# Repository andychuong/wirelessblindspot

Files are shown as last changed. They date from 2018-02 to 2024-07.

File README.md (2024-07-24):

# Wireless Blindspot Detection System

This project was designed to be an easy to install/use blindspot detection system for motor vehicles. It was inspired by the advances of technology and computed embedded into modern cars. 

This project is comprised of two unites, a receiver and a sensor. The sensor unit is attached to your rear quarter panel with a magnet and has an ultrasonic sensor attached to it. The receiver component is made to sit inside of your car with an array of LED lights to notify the driver of objects in their blindspot. 

## Technology
- Arduino
- Bluetooth
- Eagle CAD

## Hardware
- [2x SparkFun ProMicro 5v](https://www.sparkfun.com/products/12640)
- [2x xBee](https://www.sparkfun.com/products/8665)
- [Weatherproof Ultrasonic Sensor](https://www.amazon.com/Waterproof-Ultrasonic-Distance-Measuring-Transducer/dp/B01J5KZU8M)
- [Individually Addressable LED Strip](https://www.amazon.com/ALITOVE-WS2812B-Individually-Addressable-Waterproof/dp/B00ZHB9M6A)

## Images
More images [here](https://github.com/andychuong/wirelessblindspot/tree/master/Images)
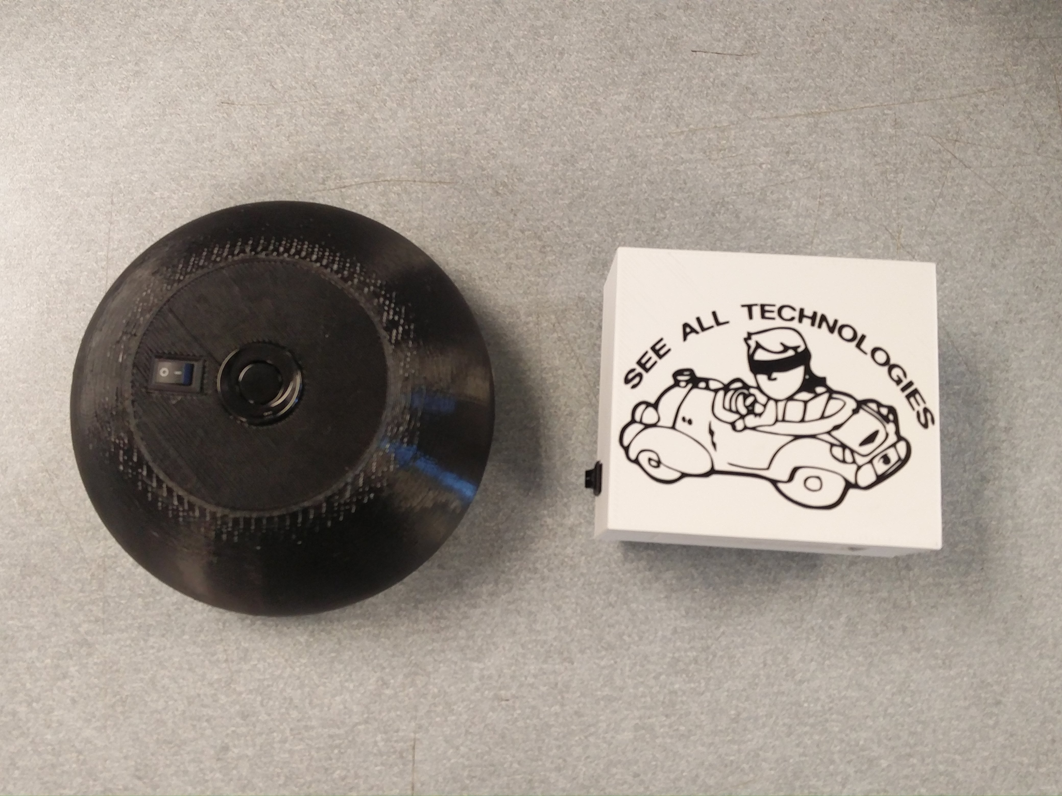
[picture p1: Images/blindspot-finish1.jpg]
Complete Units

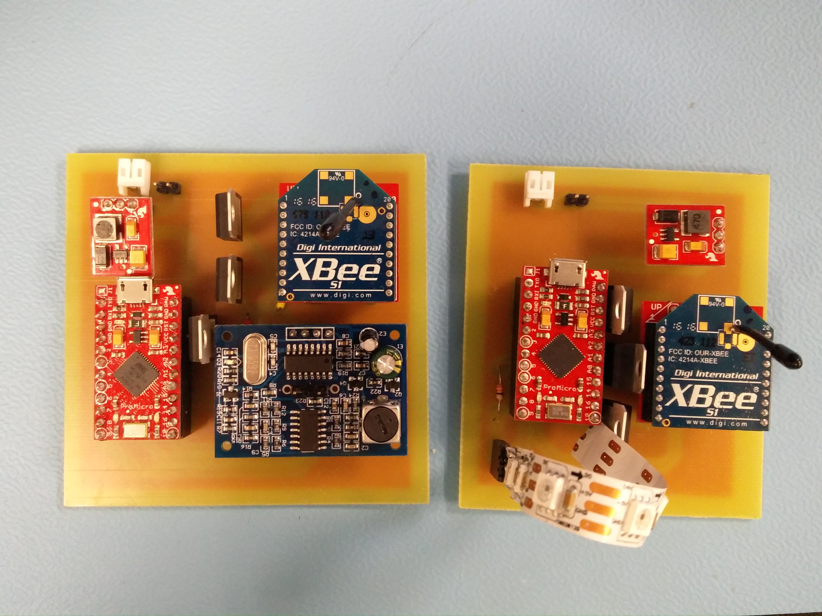
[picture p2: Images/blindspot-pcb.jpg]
Circuit boards


## Going Futher
### Built in charging solution
Currently, this project has you remove the LiPo batteries and plug them in a charger when they are out of charge. In the future, it would be nice to implement some kind of integrated setup to allow users to charge the batteries without disassembling the units. 
### Weather Proofing
The sensor unit that is attached to the exterious of the vehicle would need to have some sort of weatherproofing added to it. The addition of some sort of gaskets would greatly improve this. 
### Size Reduction
The footprint of our units isn't overly large, however I believe the size can be greatly reduced. To improve this, my first though would be to use a microcontroller such as the Adafruit Feather Bluefruit. This would combine our microcontroller with our bluetooth units. This would also solve our charging situation. Another idea would be to completely build our own circuit boards with everything we need implemented into the PCB with surface mounted components. 

---
###### Done in collaboration with Sean Connolly, Elijah Fisk, and Alex Schwartz.

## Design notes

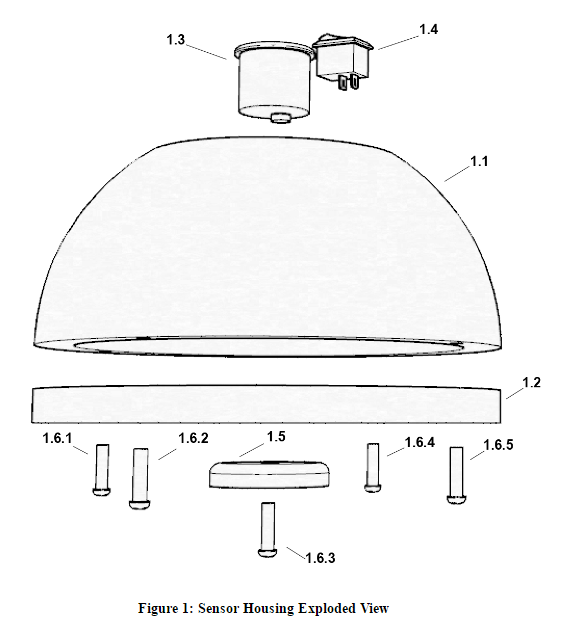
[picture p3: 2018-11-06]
Images/blindspot-sensor-exploded.png

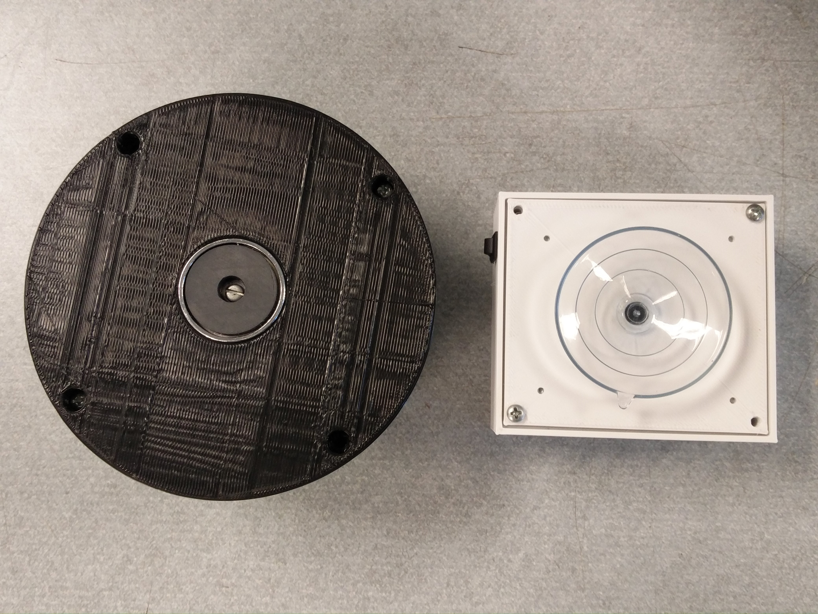
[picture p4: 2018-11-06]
Images/blindspot-finish2.jpg

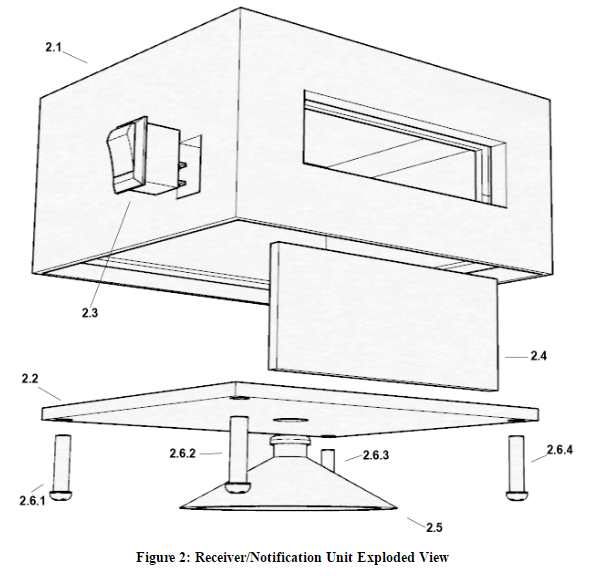
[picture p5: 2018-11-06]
Images/blindspot-receiver-exploded.png

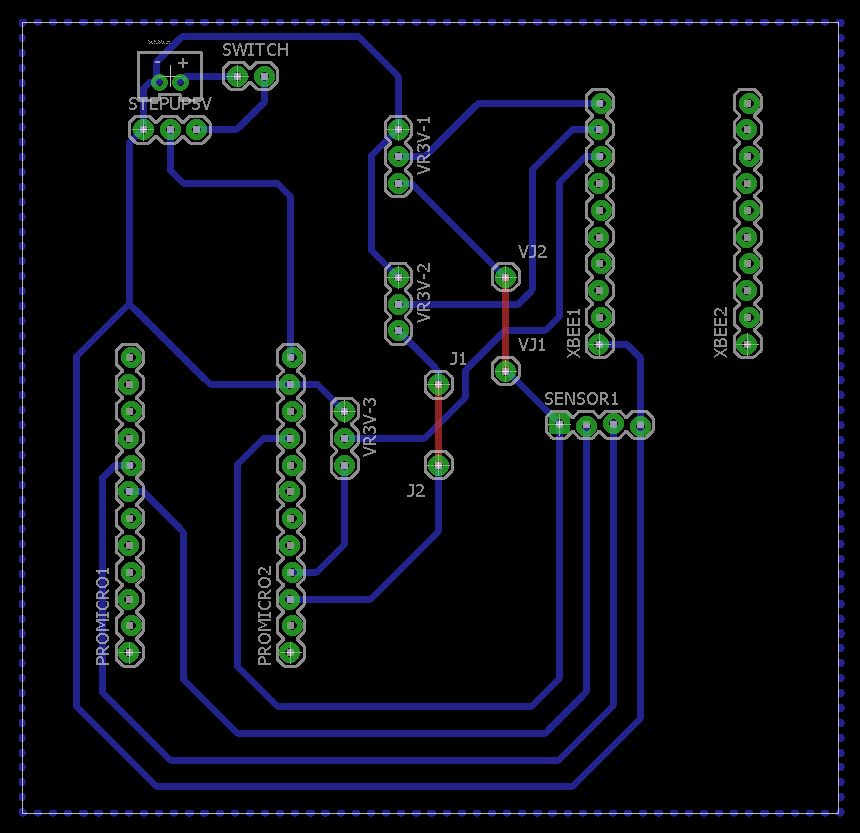
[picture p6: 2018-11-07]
Images/blindspot-sensor-eagle.png

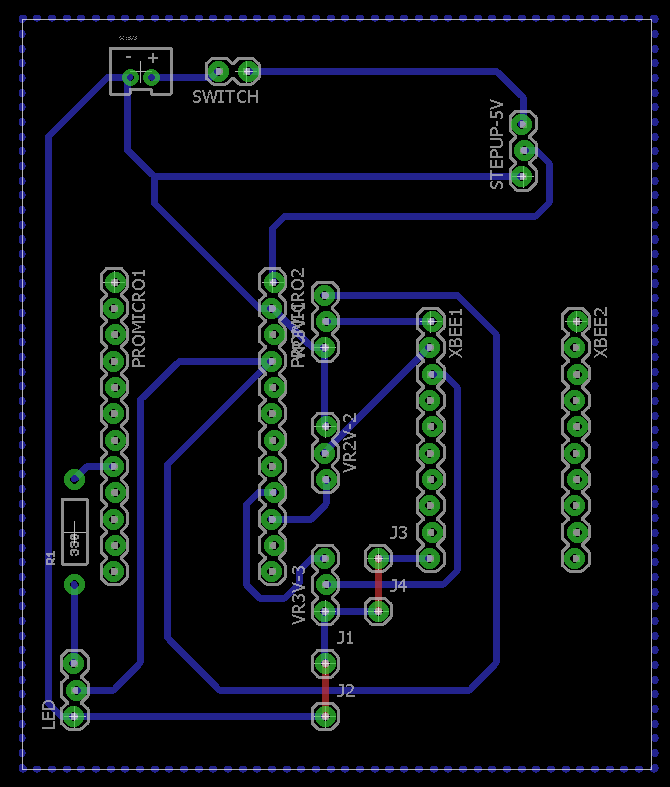
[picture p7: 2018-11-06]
Images/blindspot-receiver-eagle.png

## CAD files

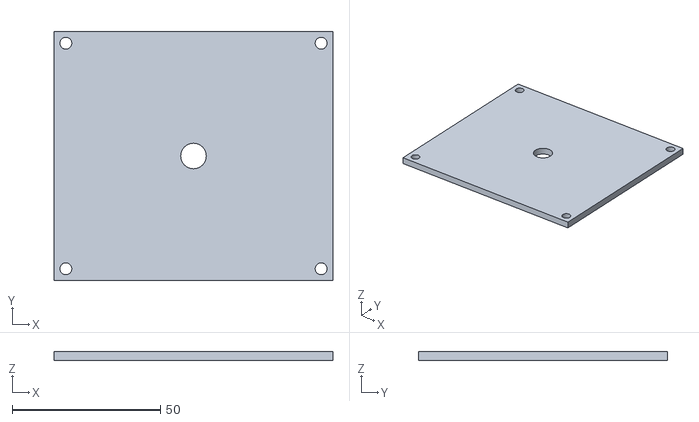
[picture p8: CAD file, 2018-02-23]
Enclosures/stl/lid.stl
94.0 x 84.0 x 3.00

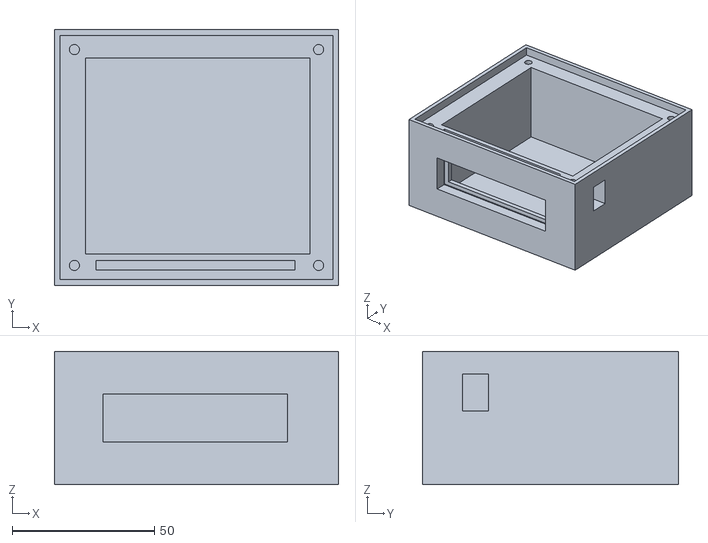
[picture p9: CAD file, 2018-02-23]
Enclosures/stl/box.stl
100.0 x 90.0 x 47.0

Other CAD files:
Enclosures/ReceiverComponentsExploded.3dm
Enclosures/SensorComponentsExploded.3dm
Enclosures/receiverEnclosure.3dm
Enclosures/sensorEnclosure.3dm

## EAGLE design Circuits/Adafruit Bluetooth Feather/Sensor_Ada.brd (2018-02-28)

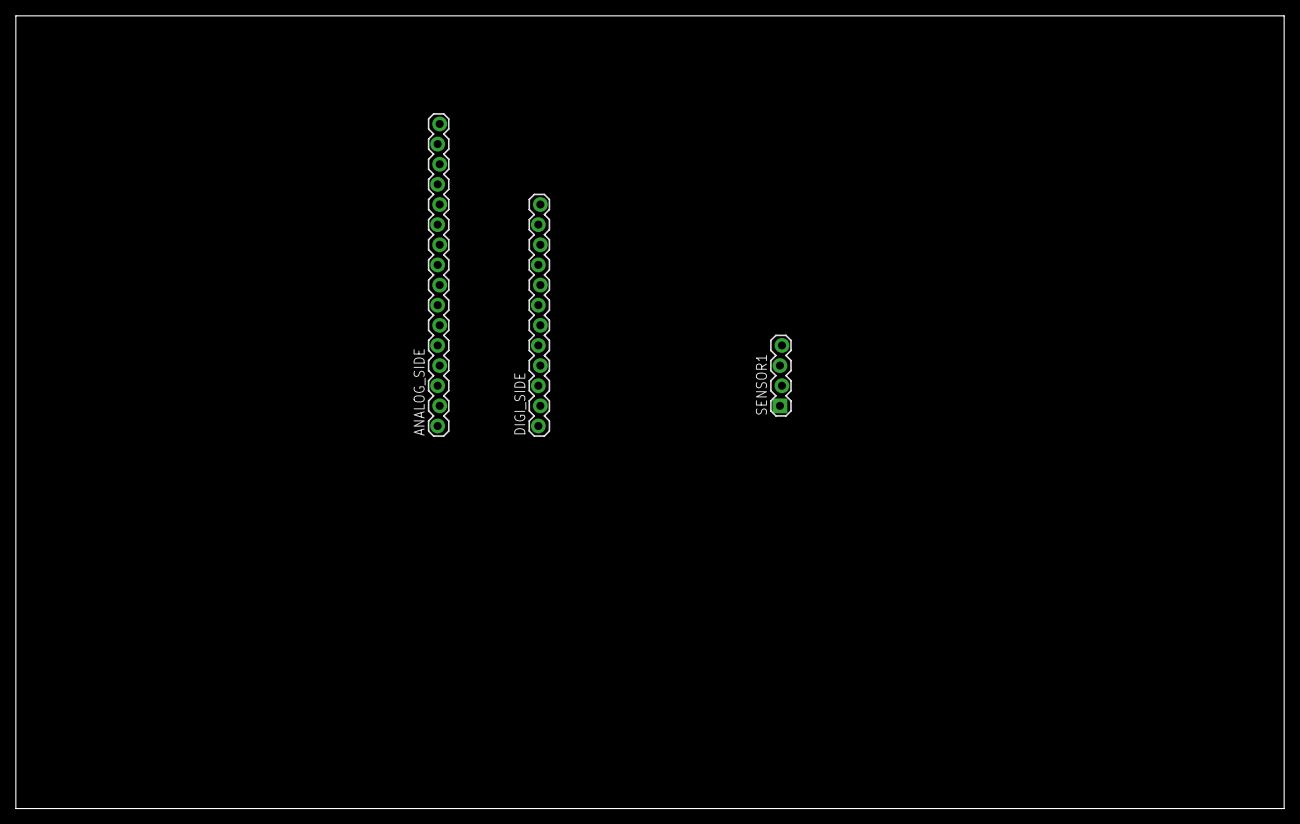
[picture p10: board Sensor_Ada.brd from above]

Board: 2 copper layers, 160.0 x 100.0 mm, 3 parts (0 on the bottom side), 3 nets, no tracks yet.

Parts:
ANALOG_SIDE: 1X16_LOCK
DIGI_SIDE: 1X12_LOCK
SENSOR1: 1X04_LOCK

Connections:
ECHO: DIGI_SIDE.1, SENSOR1.2
GND: ANALOG_SIDE.13, SENSOR1.1
TRIG: DIGI_SIDE.2, SENSOR1.3

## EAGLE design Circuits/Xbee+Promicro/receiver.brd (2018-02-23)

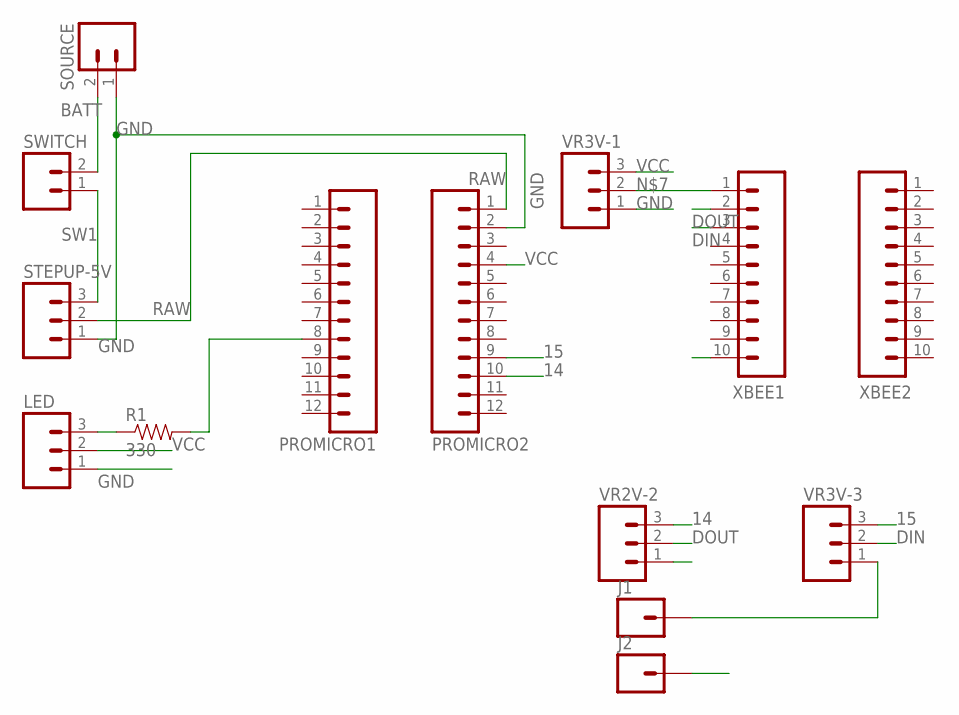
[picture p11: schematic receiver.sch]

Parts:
J1, J2: M01PTH; 1X01
LED: M03LOCK; 1X03_LOCK
PROMICRO1, PROMICRO2: M12LOCK; 1X12_LOCK
R1: 330; AXIAL-0.4
SOURCE: M02JST-PTH-VERT; JST-2-PTH-VERT
STEPUP-5V: M03LOCK; 1X03_LOCK
SWITCH: M02LOCK; 1X02_LOCK
VR2V-2, VR3V-1, VR3V-3: M03LOCK; 1X03_LOCK
XBEE1, XBEE2: M10LOCK; 1X10_LOCK

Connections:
14: PROMICRO2.10, VR2V-2.3
15: PROMICRO2.9, VR3V-3.3
BATT: SOURCE.2, SWITCH.2
DIN: VR3V-3.2, XBEE1.3
DOUT: VR2V-2.2, XBEE1.2
GND: J1.1, J2.1, LED.1, PROMICRO2.2, SOURCE.1, STEPUP-5V.1, VR2V-2.1, VR3V-1.1, VR3V-3.1
unnamed: LED.3, R1.P$1 (1)
unnamed: PROMICRO1.8, R1.P$2 (2)
unnamed: VR3V-1.2, XBEE1.1
RAW: PROMICRO2.1, STEPUP-5V.2
SW1: STEPUP-5V.3, SWITCH.1
VCC: LED.2, PROMICRO2.4, VR3V-1.3

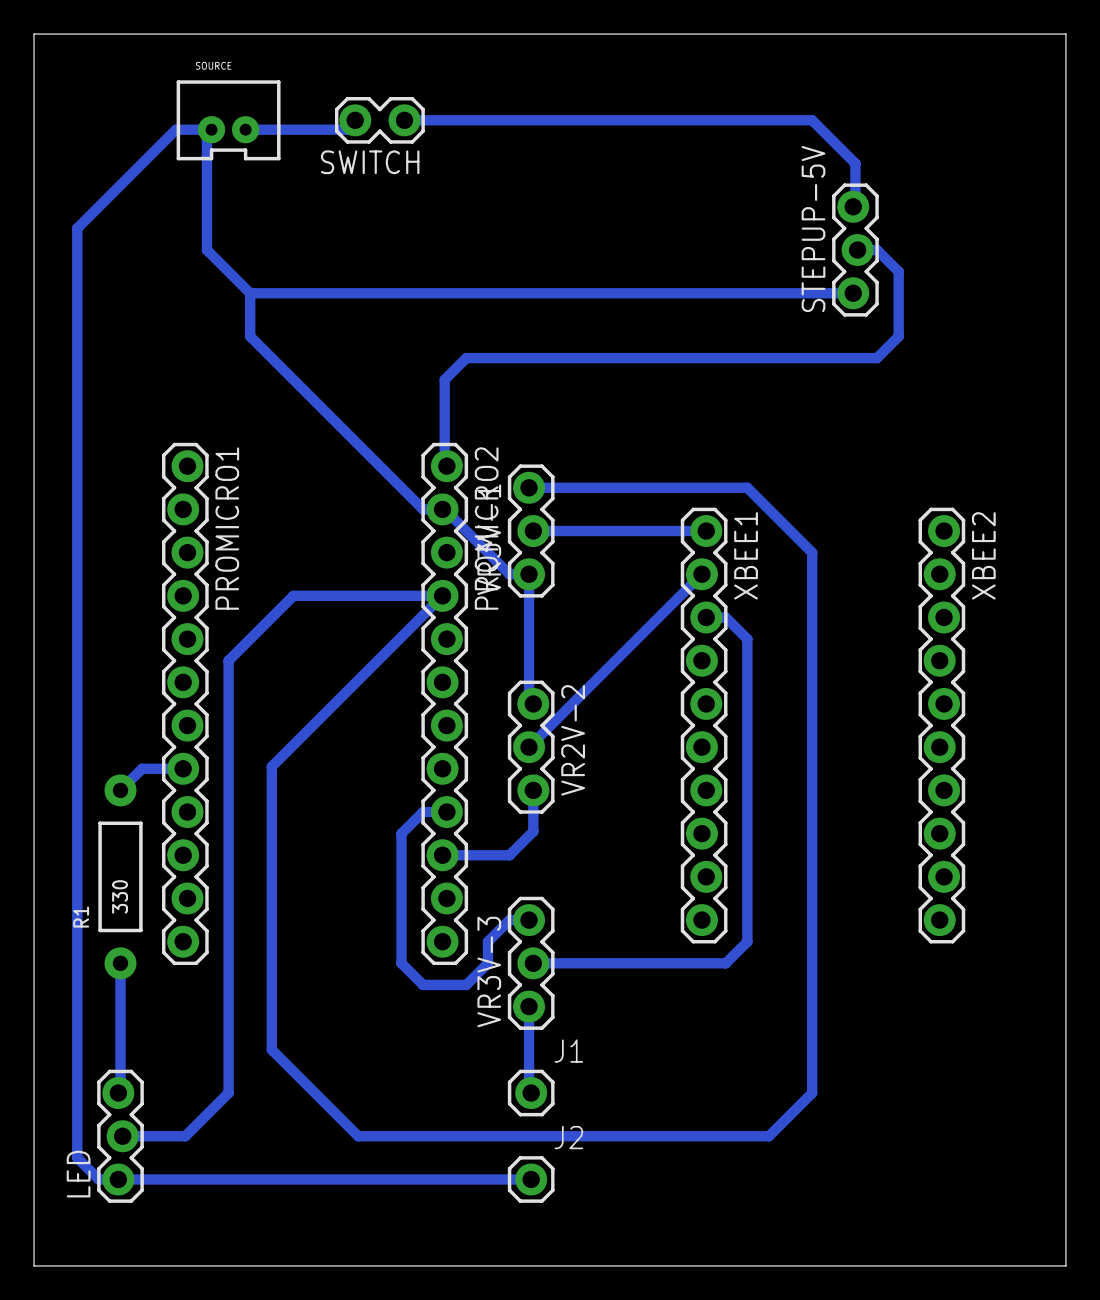
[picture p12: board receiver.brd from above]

Board: 2 copper layers, 60.6 x 72.4 mm, 14 parts (0 on the bottom side), 12 nets.

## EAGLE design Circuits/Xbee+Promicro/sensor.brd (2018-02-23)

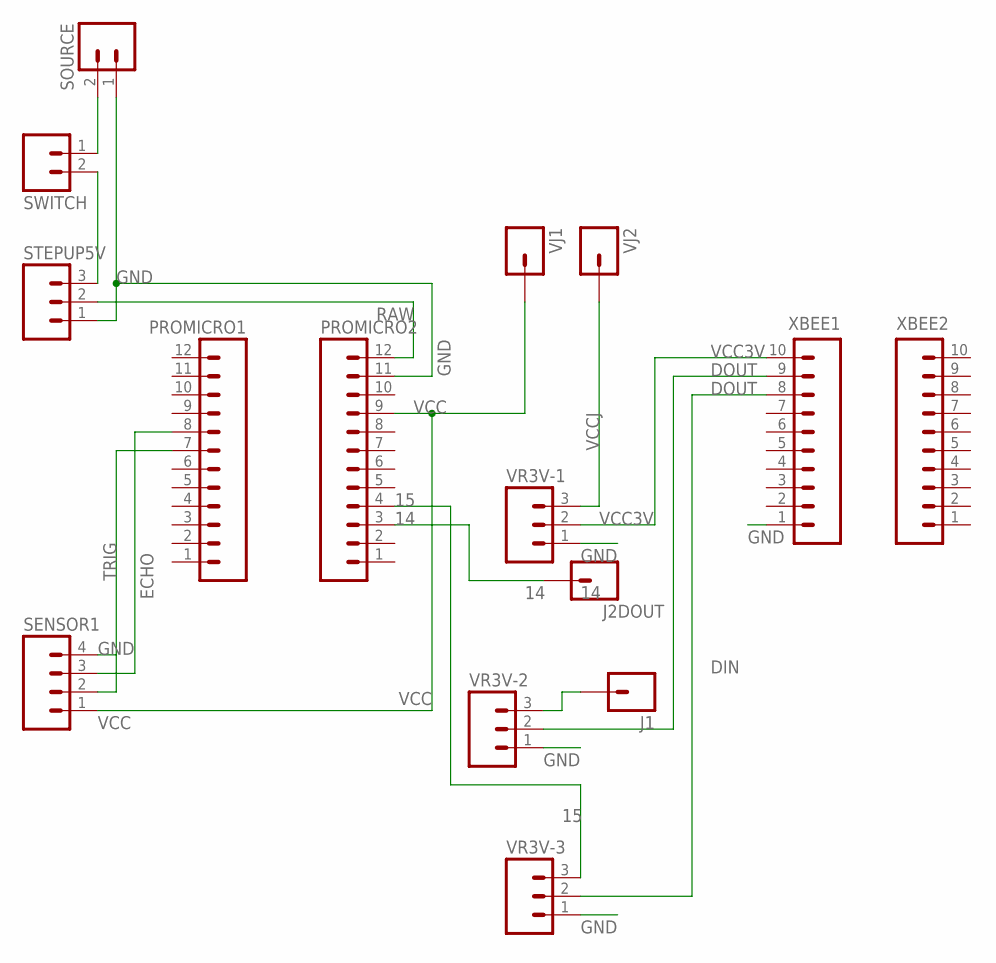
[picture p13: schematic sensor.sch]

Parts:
J1, J2: M01PTH; 1X01
PROMICRO1, PROMICRO2: M12LOCK; 1X12_LOCK
SENSOR1: M04LOCK; 1X04_LOCK
SOURCE: M02JST-PTH-VERT; JST-2-PTH-VERT
STEPUP5V: M03PTH; 1X03
SWITCH: M02PTH; 1X02
VJ1, VJ2: M01PTH; 1X01
VR3V-1, VR3V-2, VR3V-3: M03PTH; 1X03
XBEE1, XBEE2: M10LOCK; 1X10_LOCK

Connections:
14: J2.1, PROMICRO2.3
15: PROMICRO2.4, VR3V-3.3
DIN: VR3V-3.2, XBEE1.8
DOUT: VR3V-2.2, XBEE1.9
ECHO: PROMICRO1.8, SENSOR1.3
GND: PROMICRO2.11, SENSOR1.4, SOURCE.1, STEPUP5V.1, VR3V-1.1, VR3V-2.1, VR3V-3.1, XBEE1.1
unnamed: SOURCE.2, SWITCH.1
unnamed: STEPUP5V.3, SWITCH.2
unnamed: J1.1, VR3V-2.3
RAW: PROMICRO2.12, STEPUP5V.2
TRIG: PROMICRO1.7, SENSOR1.2
VCC: PROMICRO2.9, SENSOR1.1, VJ1.1
VCC3V: VR3V-1.2, XBEE1.10
VCCJ: VJ2.1, VR3V-1.3

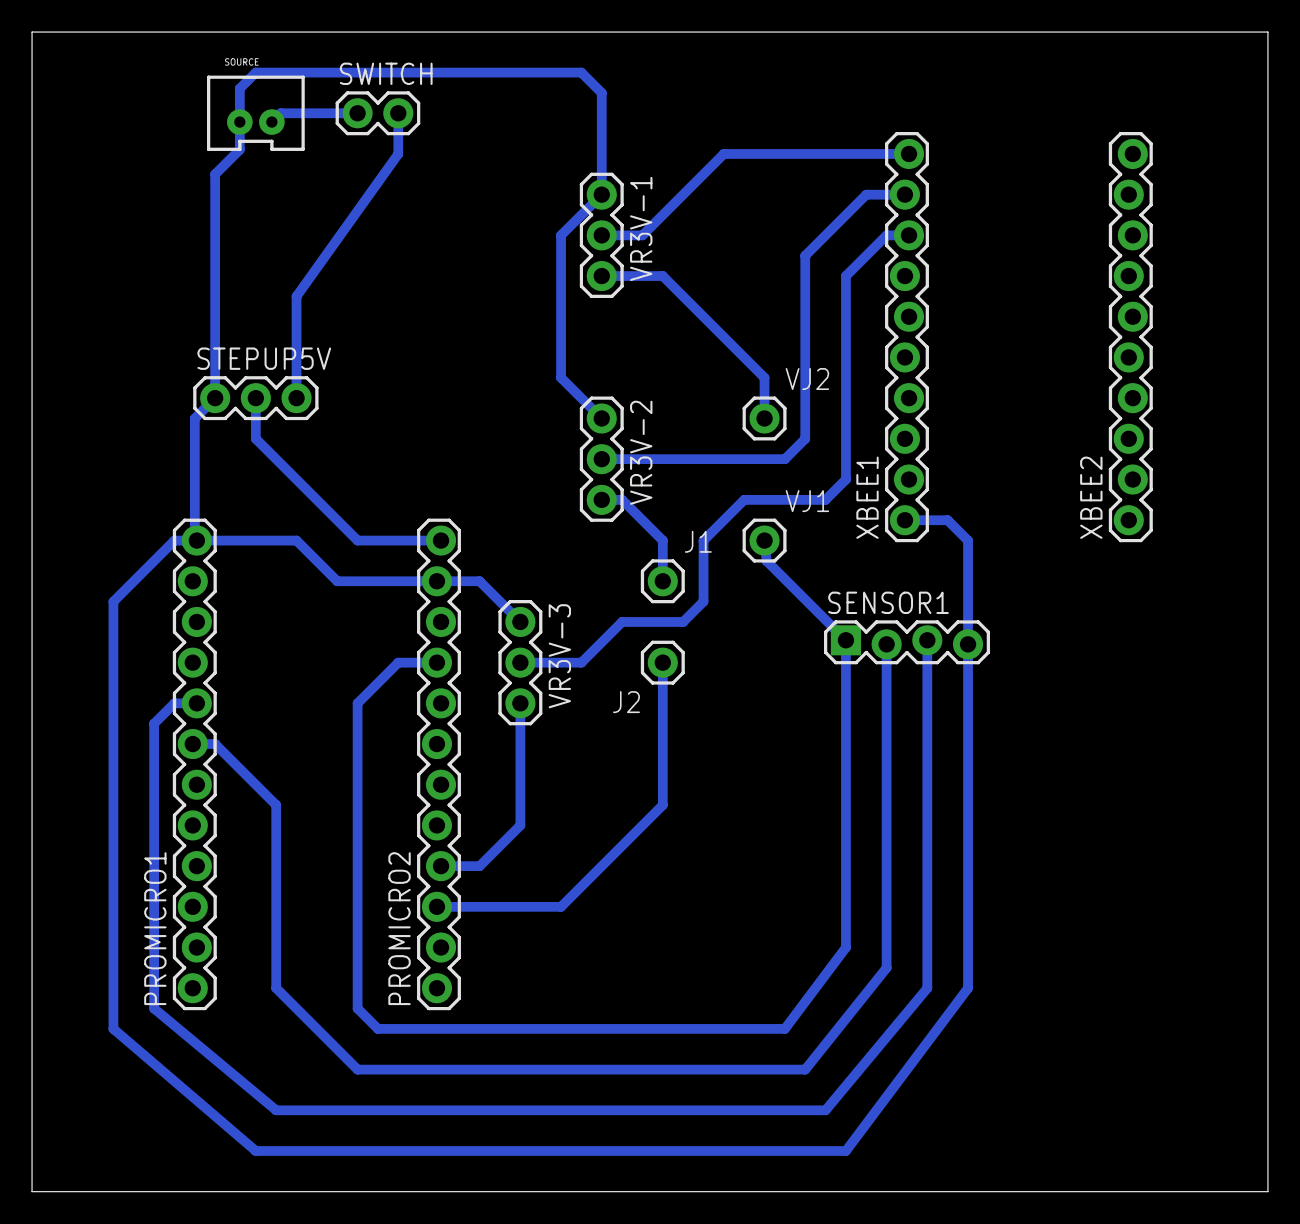
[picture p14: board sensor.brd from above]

Board: 2 copper layers, 77.1 x 72.4 mm, 15 parts (0 on the bottom side), 14 nets.

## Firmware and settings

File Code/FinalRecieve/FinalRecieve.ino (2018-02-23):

/*****************************************************************
XBee_Serial_Passthrough.ino

Set up a software serial port to pass data between an XBee Shield
and the serial monitor.

Hardware Hookup:
  The XBee Shield makes all of the connections you'll need
  between Arduino and XBee. If you have the shield make
  sure the SWITCH IS IN THE "DLINE" POSITION. That will connect
  the XBee's DOUT and DIN pins to Arduino pins 2 and 3.

*****************************************************************/

#include <Adafruit_NeoPixel.h>
#ifdef __AVR__
  #include <avr/power.h>
#endif

#define PIN 5

// Parameter 1 = number of pixels in strip
// Parameter 2 = Arduino pin number (most are valid)
// Parameter 3 = pixel type flags, add together as needed:
//   NEO_KHZ800  800 KHz bitstream (most NeoPixel products w/WS2812 LEDs)
//   NEO_KHZ400  400 KHz (classic 'v1' (not v2) FLORA pixels, WS2811 drivers)
//   NEO_GRB     Pixels are wired for GRB bitstream (most NeoPixel products)
//   NEO_RGB     Pixels are wired for RGB bitstream (v1 FLORA pixels, not v2)
//   NEO_RGBW    Pixels are wired for RGBW bitstream (NeoPixel RGBW products)
Adafruit_NeoPixel strip = Adafruit_NeoPixel(7, PIN, NEO_GRB + NEO_KHZ800);

// IMPORTANT: To reduce NeoPixel burnout risk, add 1000 uF capacitor across
// pixel power leads, add 300 - 500 Ohm resistor on first pixel's data input
// and minimize distance between Arduino and first pixel.  Avoid connecting
// on a live circuit...if you must, connect GND first.


// We'll use SoftwareSerial to communicate with the XBee:
#include <SoftwareSerial.h>
// XBee's DOUT (TX) is connected to pin 2 (Arduino's Software RX)
// XBee's DIN (RX) is connected to pin 3 (Arduino's Software TX)
SoftwareSerial XBee(14, 15); // RX, TX
const int numReadings = 10;
int readingsa[numReadings];      // the readings from the analog input
int readIndex = 0;              // the index of the current reading
int totala = 0;                  // the running total
int averagea = 0;                // the average


void setup()
{
  // Set up both ports at 9600 baud. This value is most important
  // for the XBee. Make sure the baud rate matches the config
  // setting of your XBee.
  XBee.begin(9600);
  Serial.begin(9600);
  for (int thisReading = 0; thisReading < numReadings; thisReading++) {
    readingsa[thisReading] = 0;
  }
  
  strip.begin();
  strip.show(); // Initialize all pixels to 'off'
}

void loop()
{
  /*if (Serial.available())
  { // If data comes in from serial monitor, send it out to XBee
    XBee.write(Serial.read());
  }*/
  
  if (XBee.available())
  { // If data comes in from XBee, send it out to serial monitor
   int dist = XBee.read();
   if (dist==244)
   {
   dist=500;
   
   }
    totala = totala - readingsa[readIndex];
  // read from the sensor:
  readingsa[readIndex] = dist;
  // add the reading to the total:
  totala = totala + readingsa[readIndex];
   // advance to the next position in the array:
  readIndex = readIndex + 1;

  // if we're at the end of the array...
  if (readIndex >= numReadings) {
    // ...wrap around to the beginning:
    readIndex = 0;
  }

  // calculate the average:
    averagea = totala / numReadings;
  //  averagey = totaly / numReadings;
    //averagez = totalz / numReadings;
  
  Serial.print(dist);
  Serial.print("\t");
  Serial.println(averagea);
  if (averagea>200)
  {
  colorWipe(strip.Color(127, 127, 127), 10); // White
  }
   /* else if (101<averagea<450){
     colorWipe(strip.Color(0, 127, 0), 10); // Green 
    }
      else if (51<averagea<100){
      colorWipe(strip.Color(127, 127, 0), 10); // Yellow  
  }
  */
        else if (averagea<200) {
  colorWipe(strip.Color(127, 0, 0), 10); // Red  
  
  }
  delay(100);
    }
    else{
        rainbow(5); 
    }
}


// Fill the dots one after the other with a color
void colorWipe(uint32_t c, uint8_t wait) {
  for(uint16_t i=0; i<strip.numPixels(); i++) {
    strip.setPixelColor(i, c);
    strip.show();
    delay(wait);
  }
}

void rainbow(uint8_t wait) {
  uint16_t i, j;

  for(j=0; j<256; j++) {
    for(i=0; i<strip.numPixels(); i++) {
      strip.setPixelColor(i, Wheel((i+j) & 255));
    }
    strip.show();
    delay(wait);
  }
}

//Theatre-style crawling lights.
void theaterChase(uint32_t c, uint8_t wait) {
  for (int j=0; j<10; j++) {  //do 10 cycles of chasing
    for (int q=0; q < 3; q++) {
      for (int i=0; i < strip.numPixels(); i=i+3) {
        strip.setPixelColor(i+q, c);    //turn every third pixel on
      }
      strip.show();

      delay(wait);

      for (int i=0; i < strip.numPixels(); i=i+3) {
        strip.setPixelColor(i+q, 0);        //turn every third pixel off
      }
    }
  }
}

uint32_t Wheel(byte WheelPos) {
  WheelPos = 255 - WheelPos;
  if(WheelPos < 85) {
    return strip.Color(255 - WheelPos * 3, 0, WheelPos * 3);
  }
  if(WheelPos < 170) {
    WheelPos -= 85;
    return strip.Color(0, WheelPos * 3, 255 - WheelPos * 3);
  }
  WheelPos -= 170;
  return strip.Color(WheelPos * 3, 255 - WheelPos * 3, 0);
}

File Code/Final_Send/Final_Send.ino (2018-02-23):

#include <SoftwareSerial.h>
// XBee's DOUT (TX) is connected to pin 14 (Arduino's Software RX)
// XBee's DIN (RX) is connected to pin 15 (Arduino's Software TX)
SoftwareSerial XBee(14, 15); // RX, TX
// ---------------------------------------------------------------------------
// Example NewPing library sketch that does a ping about 20 times per second.
// ---------------------------------------------------------------------------
#include <NewPing.h>

#define TRIGGER_PIN  3  // RX Arduino pin tied to trigger pin on the ultrasonic sensor.
#define ECHO_PIN     2  // TX Arduino pin tied to echo pin on the ultrasonic sensor.
#define MAX_DISTANCE 450 // Maximum distance we want to ping for (in centimeters). Maximum sensor distance is rated at 400-500cm.

NewPing sonar(TRIGGER_PIN, ECHO_PIN, MAX_DISTANCE); // NewPing setup of pins and maximum distance.
void setup() {
  Serial.begin(9600); // Open serial monitor at 115200 baud to see ping results.
  //pinMode(LEDPin, OUTPUT);
  XBee.begin(9600);
}

void loop() {
  delay(50);                      // Wait 50ms between pings (about 20 pings/sec). 29ms should be the shortest delay between pings.
  unsigned int uS = sonar.ping_median(); // Returning median pings at a rate of 3Hz.
  int distance = uS / US_ROUNDTRIP_CM;
  if (distance < 5){
    distance=500;
  }
  
  XBee.write(distance);
 // Serial.print("Ping: ");
  Serial.println(distance); // Convert ping time to distance and print result (0 = outside set distance range, no ping echo)
}

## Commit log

2018-02-23 Version 1 Prototyping
    [ReceiverComponentsExploded.3dm, SensorComponentsExploded.3dm, box.stl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]
2018-02-28 Adafruit featherboard prototypes
    [Sensor_Ada.brd, Sensor_Ada.sch]
2018-11-07 sensor pcb drawing

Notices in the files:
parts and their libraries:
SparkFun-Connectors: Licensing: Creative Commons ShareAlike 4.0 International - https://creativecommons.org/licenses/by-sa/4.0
